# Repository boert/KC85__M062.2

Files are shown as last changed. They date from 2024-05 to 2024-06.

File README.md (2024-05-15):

# M062.2, Speichermodul für KC85
TTL-Version des Speichermodul M062 für den KC85/3..4..5 mit 32 kByte RAM (nichtflüchtig) oder 64 kByte EPROM

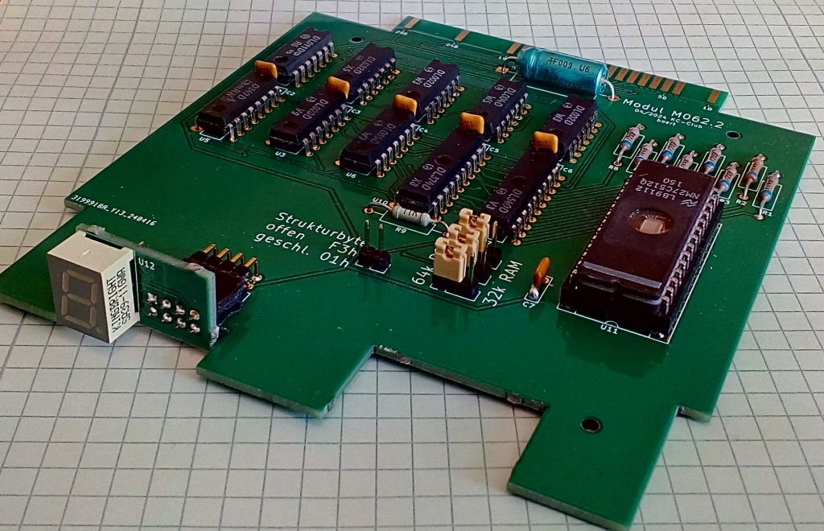
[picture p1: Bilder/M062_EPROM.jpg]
M062.2 bestückt mit 64 kByte EPROM


## Motivation
Um die Erweiterung der EPROM-Generator-Software [^1] zu testen, wurde eine passende Hardware benötigt.
Das M062 von E. Müller ist ein Speichermodul für den KC85 aus Mühlhausen, das entweder mit einem EPROM (64 kByte) oder einem nichtflüchtgen SRAM (32 kByte) bestückt werden kann. Durch den Einsatz eines CPLD werden im Original nur vier Schaltkreise benötigt.

Die hier vorgestellte Lösung entstand auf Basis einer Schaltungsbeschreibung in VHDL.
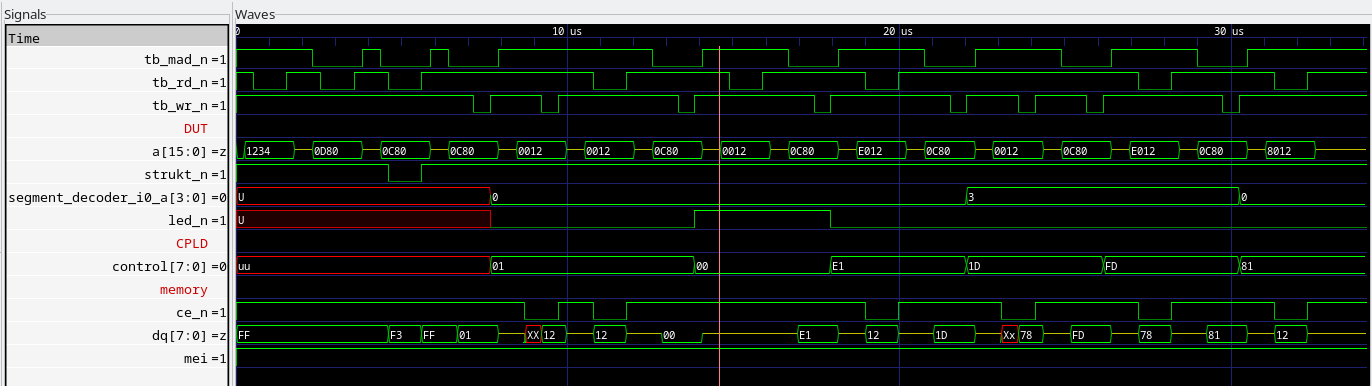
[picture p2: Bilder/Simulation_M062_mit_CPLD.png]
Simulation der Schaltungs mit ghld und Darstellung mit GTKwave

Mit Hilfe von yosys [^2] und dem ghdl-plugin [^3] ist es möglich aus der Schaltungsbeschreibung eine Netzliste zu erzeugen, die Elemente aus einer bereitgestellten TTL-Bibliothek verwendet.

<p align="center">
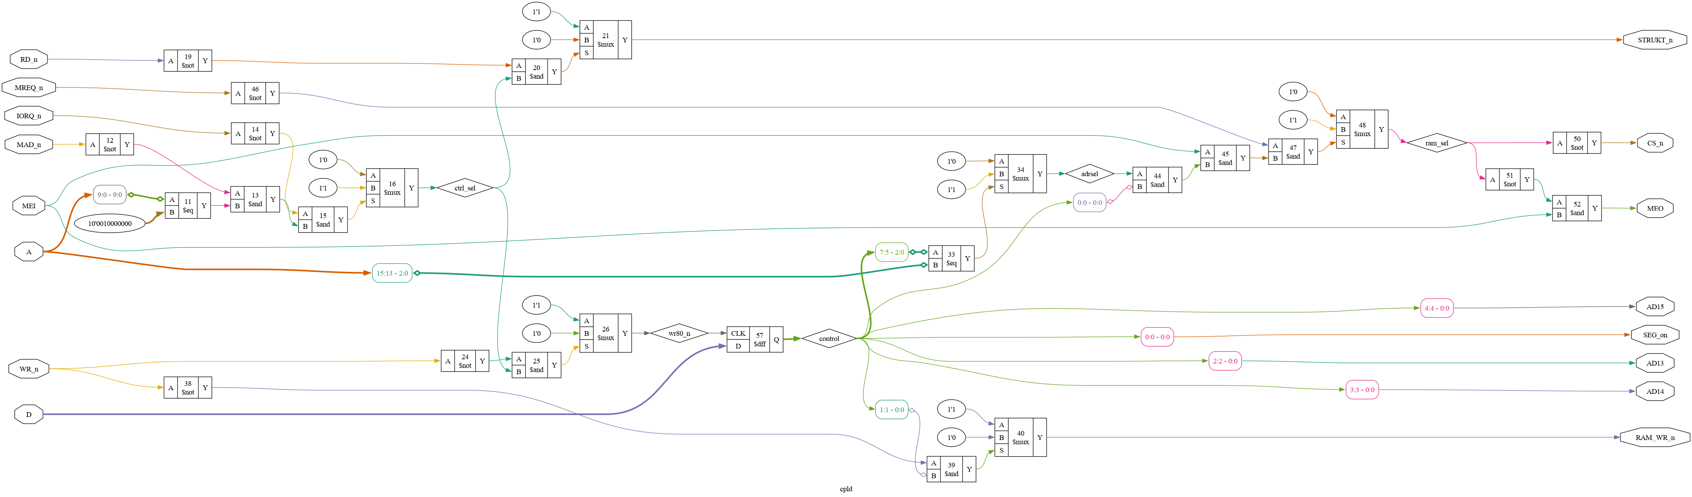
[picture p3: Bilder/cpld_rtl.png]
Synthetisierte Schaltung
  
&nbsp;
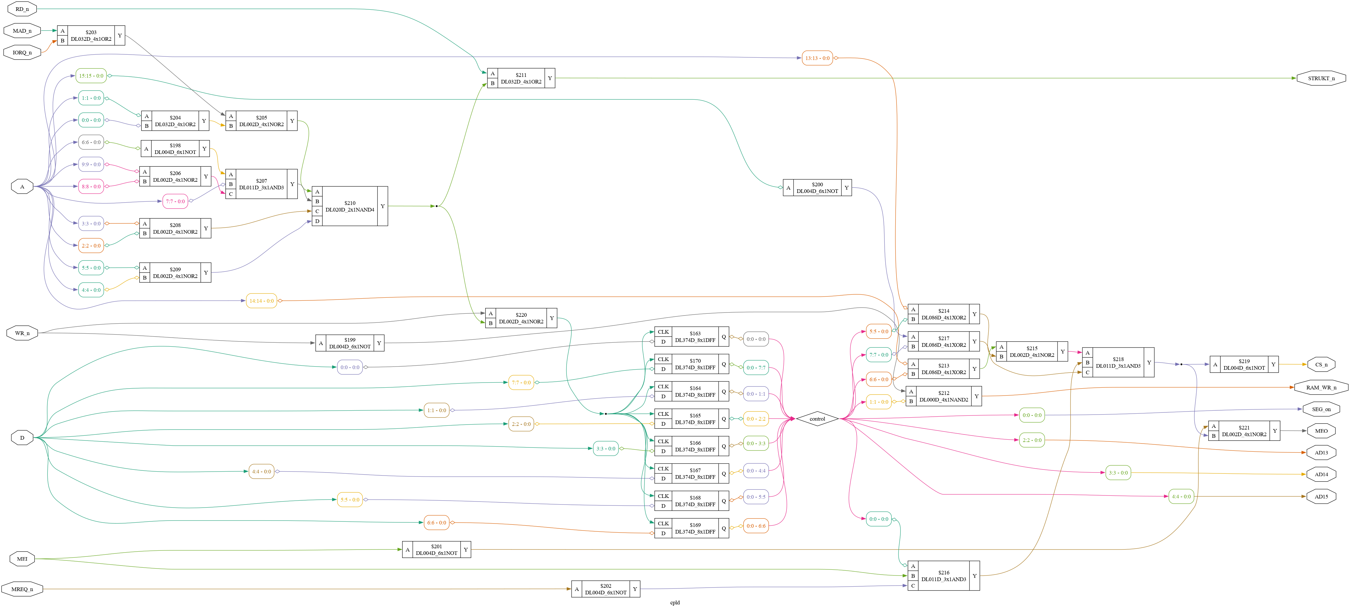
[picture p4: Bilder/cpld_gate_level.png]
Mapping auf TTL-Schaltkreise
  
</p>

Diese Netzliste wurde als Basis für den Schaltplan herangezogen.
Inklusive Speicher werden nun elf Schaltkreise benötigt.

Änderungen gegenüber dem Original
- Einsatz diskreter TTL-Schaltkreise statt CPLD
- Unterstützung für Schreibschutzbit W im Steuerbyte
- Strukturbyte zwischen F3h und 01h (Autostart) umschaltbar

Übernommen wurde die Idee mit der kleinen Zusatzplatine für die Segmentanzeige.

## Nutzung
Das Steuerbyte ist wie folgt aufgebaut:

Bit       | 7 | 6 | 5 | 4 | 3 | 2 | 1 | 0
--------- | - | - | - | - | - | - | - | -
Bedeutung | A | A | A | S | S | S | W | M

Das Speichermodul kann aus dem System CAOS mit dem Befehl SWITCH geschaltet werden.

Bit 7 | Bit 6 | Bit 5 | Adressauswahl A
----- | ----- | ----- | ---------------
0 | 0 | 0 | 0000h
0 | 0 | 1 | 2000h
0 | 1 | 0 | 4000h
0 | 1 | 1 | 6000h
1 | 0 | 0 | 8000h
1 | 0 | 1 | A000h
1 | 1 | 0 | C000h
1 | 1 | 1 | E000h

Bit 4 | Bit 3 | Bit 2 | Segment S
----- | ----- | ----- | ---------
0 | 0 | 0 | 0
0 | 0 | 1 | 1
0 | 1 | 0 | 2
0 | 1 | 1 | 3
1 | 0 | 0 | 4
1 | 0 | 1 | 5
1 | 1 | 0 | 6
1 | 1 | 1 | 7

Die Segmente 4 bis 7 existieren nur bei Bestückung mit 64 kByte EPROM.

Bit 1 | Schreibschutz W
----- | ------
0 | aktiv (read only)
1 | inaktiv (read write)

Bit 0 | Modulzustand M
----- | ------
0 | inaktiv
1 | aktiv

### Beispiel
Angenommen das Modul M062.2 steckt im Modulschacht 0C. 

Um das Segement 3 im Speicher auf Adresse 4000h im Modus Schreiben/Lesen zu aktivieren, wird der CAOS-Befehl "SWITCH C 4F" verwendet. 

Um das Segement 7 im Speicher auf Adresse C000h im Modul Nur-Lesen zu aktivieren, wird der CAOS-Befehl "SWITCH C DD" verwendet.

## Links
[^1]: https://github.com/boert/KC85__M037_segmented_ROM/tree/main/EPROM-Generator
[^2]: https://yosyshq.net/yosys/
[^3]: https://github.com/ghdl/ghdl-yosys-plugin

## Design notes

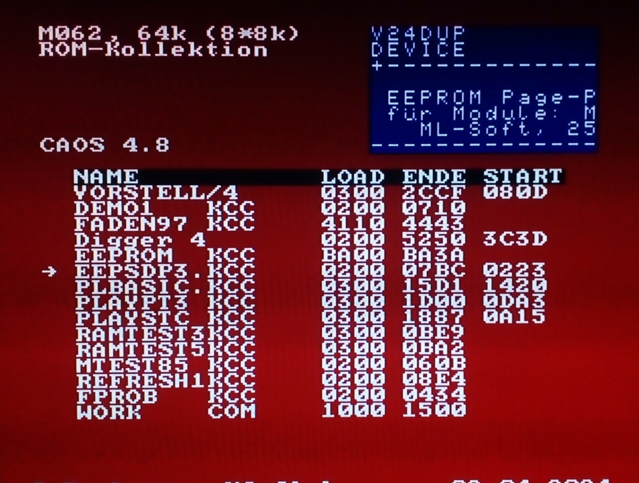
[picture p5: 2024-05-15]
EPROM-Images/M062__Utilitys_KC854.jpg

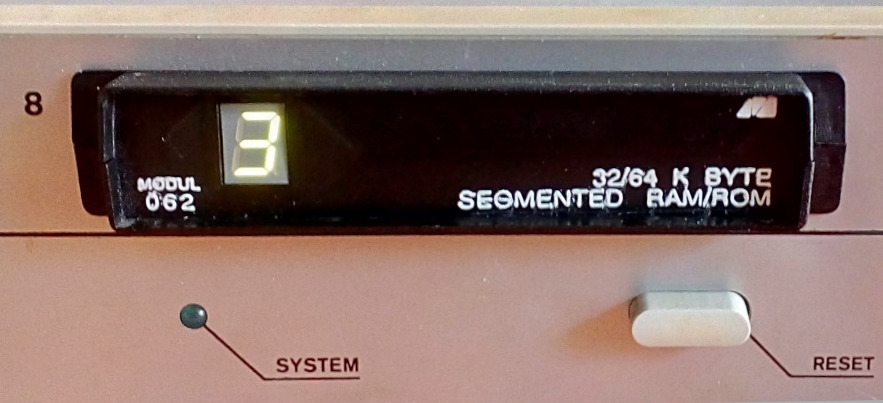
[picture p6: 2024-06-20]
Modulfrontblende__Prototyp/Bilder/M062_im_Schacht_08.jpg

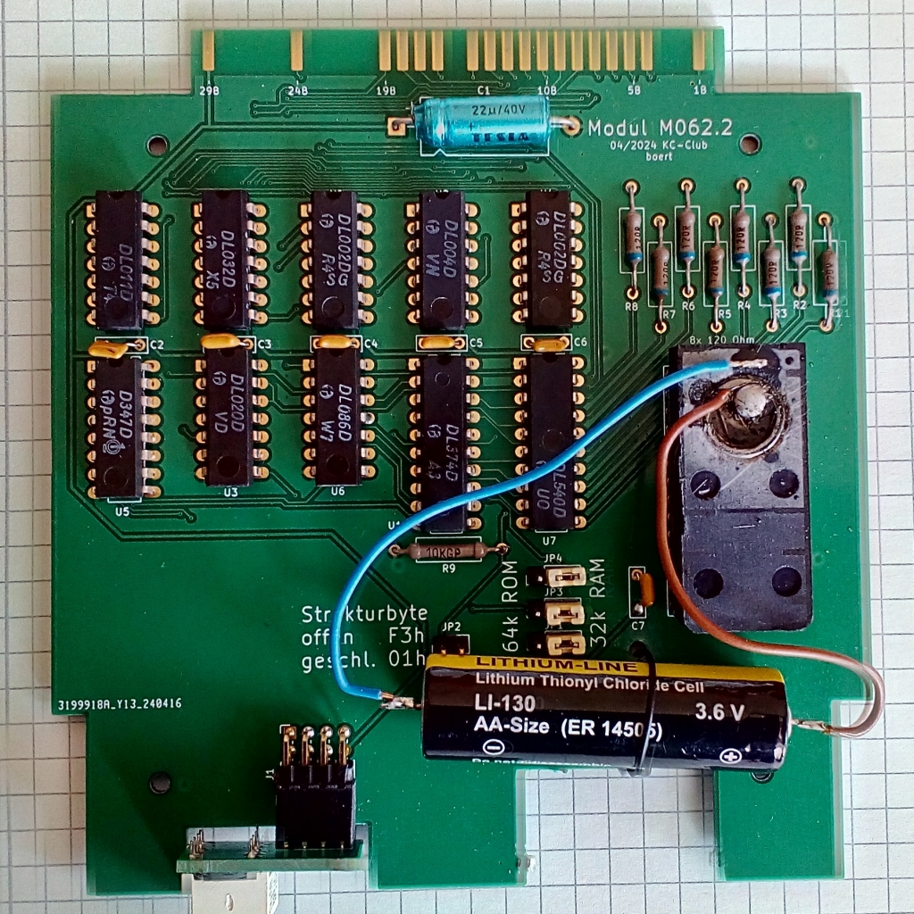
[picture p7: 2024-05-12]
Bilder/M062_NVRAM.jpg

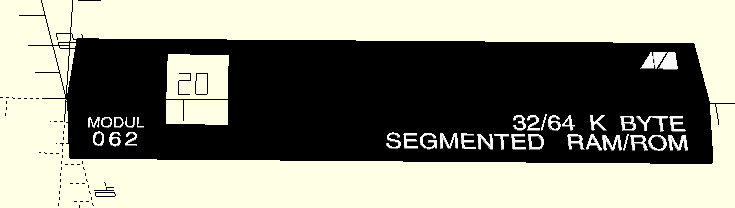
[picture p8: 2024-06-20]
Modulfrontblende__Prototyp/Bilder/M062_Frontblende__scad.png

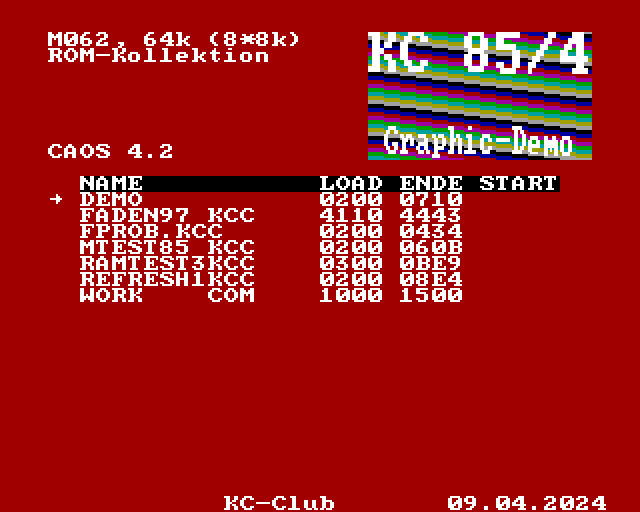
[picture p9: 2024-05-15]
EPROM-Images/M062__7_Tools_KC854.png

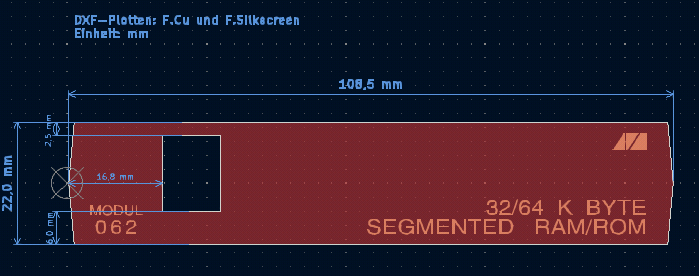
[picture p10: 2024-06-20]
Modulfrontblende__Prototyp/Bilder/M062_Frontblende__kicad.png

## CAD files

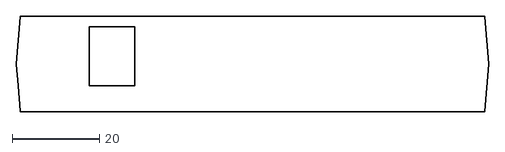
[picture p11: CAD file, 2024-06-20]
Modulfrontblende__Prototyp/DXF/M062_Frontblende-F_Cu.dxf
108.5 x 22.0

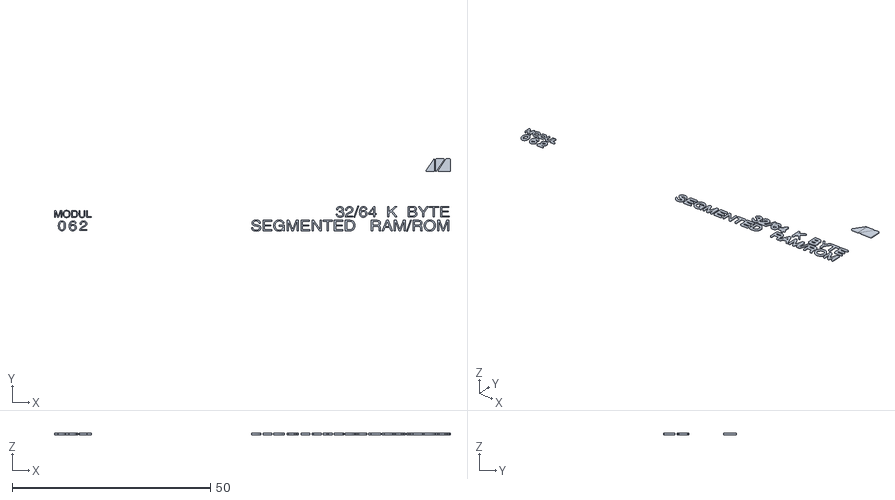
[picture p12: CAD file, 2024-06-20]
Modulfrontblende__Prototyp/OpenSCAD/M062_Frontblende__Schrift.stl
100.0 x 18.3 x 0.4

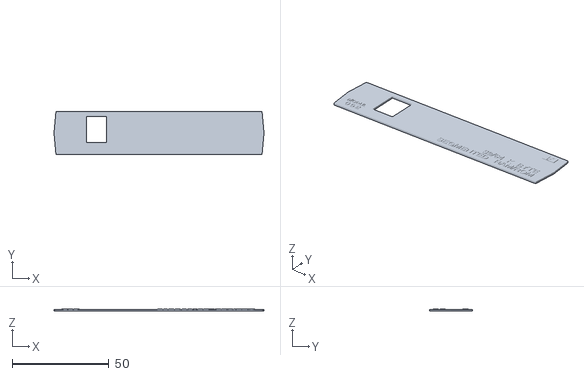
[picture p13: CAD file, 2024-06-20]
Modulfrontblende__Prototyp/OpenSCAD/M062_Frontblende__komplett.stl
108.5 x 22.0 x 1.29

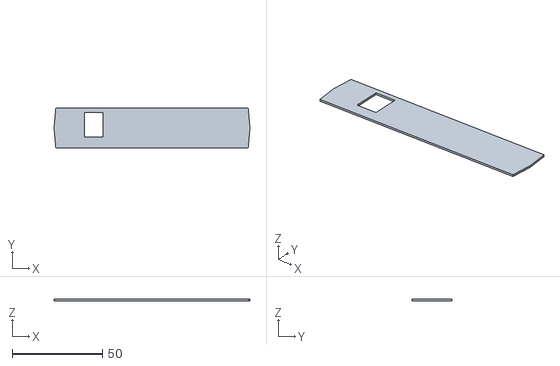
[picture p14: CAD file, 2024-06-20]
Modulfrontblende__Prototyp/OpenSCAD/M062_Frontblende__Blende_einzeln.stl
108.5 x 22.0 x 0.9

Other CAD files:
Modulfrontblende__Prototyp/OpenSCAD/M062_Frontblende.scad
Modulfrontblende__Prototyp/DXF/M062_Frontblende-F_Silkscreen.dxf

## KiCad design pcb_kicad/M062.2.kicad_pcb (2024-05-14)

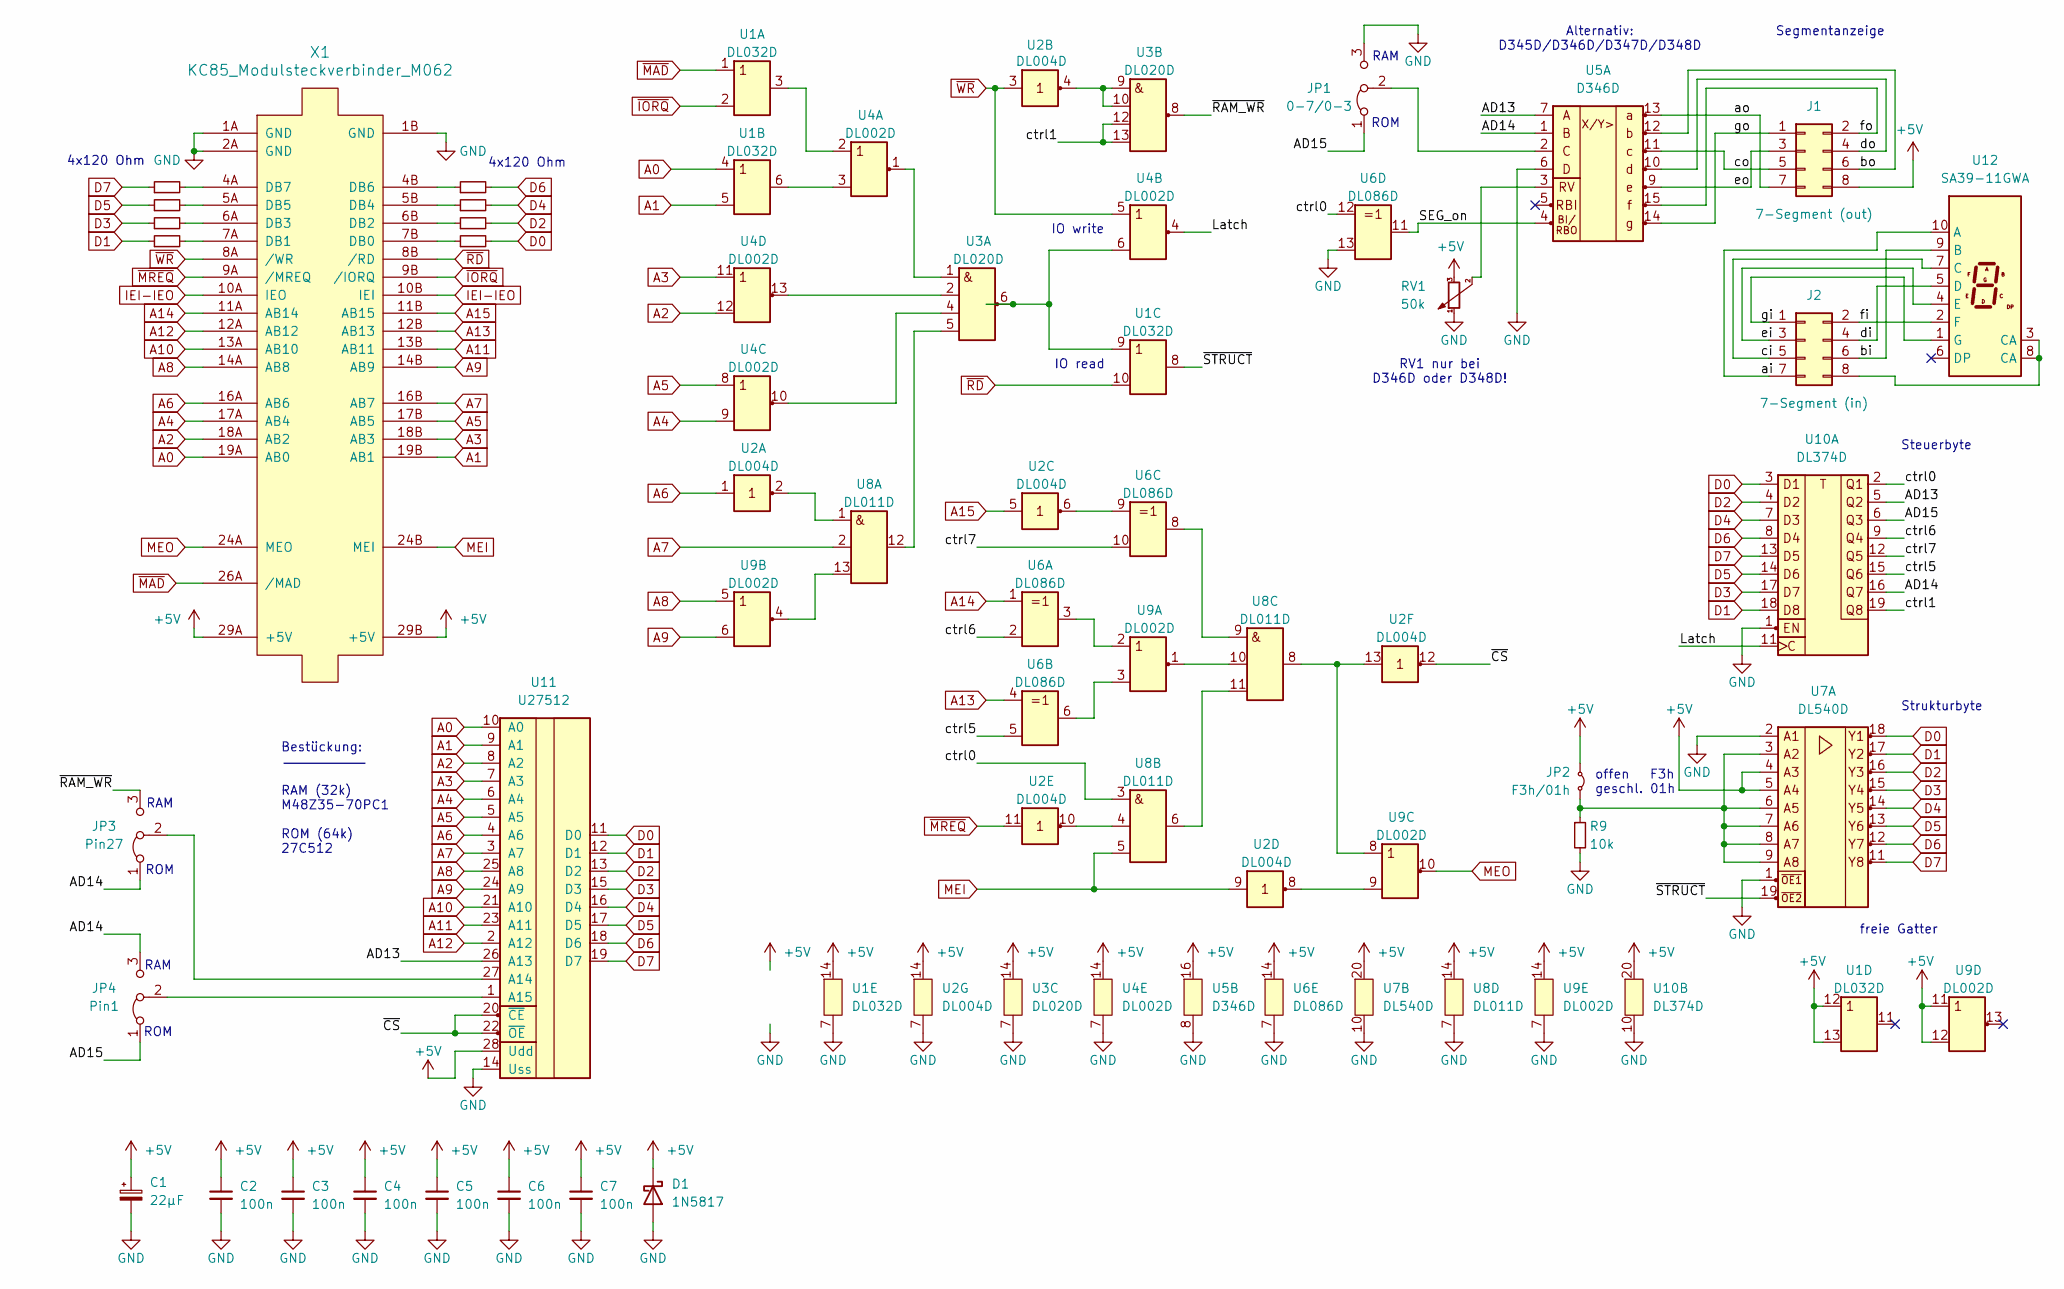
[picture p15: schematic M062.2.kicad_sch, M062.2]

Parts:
C1: 22µF; CP_Axial_L18.0mm_D8.0mm_P25.00mm_Horizontal
C2, C3, C4, C5, C6, C7: 100n; C_Rect_L7.0mm_W2.0mm_P5.00mm
D1: 1N5817; D_DO-41_SOD81_P10.16mm_Horizontal
J1: 7-Segment (out); PinSocket_2x04_P2.54mm_Horizontal
J2: 7-Segment (in); PinHeader_2x04_P2.54mm_Vertical
JP1: 0-7/0-3; PinHeader_1x03_P2.54mm_Vertical
JP2: F3h/01h; PinHeader_1x02_P2.54mm_Vertical
JP3: Pin27; PinHeader_1x03_P2.54mm_Vertical
JP4: Pin1; PinHeader_1x03_P2.54mm_Vertical
R1, R2, R3, R4, R5, R6, R7, R8: 120; R_Axial_DIN0309_L9.0mm_D3.2mm_P15.24mm_Horizontal
R9: 10k; R_Axial_DIN0309_L9.0mm_D3.2mm_P15.24mm_Horizontal
RV1: 50k; Potentiometer_ACP_CA9-V10_Vertical
U1: DL032D; DIP-14_W7.62mm_LongPads
U2: DL004D; DIP-14_W7.62mm_LongPads
U3: DL020D; DIP-14_W7.62mm_LongPads
U4, U9: DL002D; DIP-14_W7.62mm_LongPads
U5: D346D; DIP-16_W7.62mm_LongPads
U6: DL086D; DIP-14_W7.62mm_LongPads
U7: DL540D; DIP-20_W7.62mm_LongPads
U8: DL011D; DIP-14_W7.62mm_LongPads
U10: DL374D; DIP-20_W7.62mm_LongPads
U11: U27512; DIP-28_W15.24mm_Socket_LongPads
U12: SA39-11GWA; Sx39-1xxxxx
X1: KC85_Modulsteckverbinder_M062; KC85_Modul_M062

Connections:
+5V: C1.1, C2.1, C3.1, C4.1, C5.1, C6.1, C7.1, D1.1 (K), J1.8, JP2.2 (B), RV1.3, U1.12 (A4), U1.13 (B4), U1.14 (Vcc), U2.14 (Vcc), U3.14 (Vcc), U4.14 (Vcc), U5.16 (Vcc), U6.14 (Vcc), U7.4 (A3), U7.5 (A4), U7.20 (Vcc), U8.14 (Vcc), U9.11 (A4), U9.12 (B4), U9.14 (Vcc), U10.20 (Vcc), U11.28 (Udd), X1.29A (+5V), X1.29B (+5V)
/AD13: U5.7 (A), U10.5 (Q2), U11.26 (A13)
/AD14: JP3.1 (A), JP4.3 (B), U5.1 (B), U10.16 (Q7)
/AD15: JP1.1 (A), JP4.1 (A), U10.6 (Q3)
/Latch: U4.4 (Y2), U10.11 (C)
/SEG_on: U5.4 (BI/RBO), U6.11 (Y4)
/ai: J2.7, U12.10 (A)
/ao: J1.7, U5.13 (a)
/bi: J2.6, U12.9 (B)
/bo: J1.6, U5.12 (b)
/ci: J2.5, U12.7 (C)
/co: J1.5, U5.11 (c)
/ctrl0: U6.12 (A4), U8.3 (A2), U10.2 (Q1)
/ctrl1: U3.12 (C2), U3.13 (D2), U10.19 (Q8)
/ctrl5: U6.5 (B2), U10.15 (Q6)
/ctrl6: U6.2 (B1), U10.9 (Q4)
/ctrl7: U6.10 (B3), U10.12 (Q5)
/di: J2.4, U12.5 (D)
/do: J1.4, U5.10 (d)
/ei: J2.3, U12.4 (E)
/eo: J1.3, U5.9 (e)
/fi: J2.2, U12.2 (F)
/fo: J1.2, U5.15 (f)
/gi: J2.1, U12.1 (G)
/go: J1.1, U5.14 (g)
/~CS: U2.12 (Y6), U11.20 (~CE), U11.22 (~OE)
/~RAM_WR: JP3.3 (B), U3.8 (Y2)
/~STRUCT: U1.8 (Y3), U7.19 (~OE2)
A0: U1.4 (A2), U11.10 (A0), X1.19A (AB0)
A1: U1.5 (B2), U11.9 (A1), X1.19B (AB1)
A2: U4.12 (B4), U11.8 (A2), X1.18A (AB2)
A3: U4.11 (A4), U11.7 (A3), X1.18B (AB3)
A4: U4.9 (B3), U11.6 (A4), X1.17A (AB4)
A5: U4.8 (A3), U11.5 (A5), X1.17B (AB5)
A6: U2.1 (A1), U11.4 (A6), X1.16A (AB6)
A7: U8.2 (B1), U11.3 (A7), X1.16B (AB7)
A8: U9.5 (A2), U11.25 (A8), X1.14A (AB8)
A9: U9.6 (B2), U11.24 (A9), X1.14B (AB9)
A10: U11.21 (A10), X1.13A (AB10)
A11: U11.23 (A11), X1.13B (AB11)
A12: U11.2 (A12), X1.12A (AB12)
A13: U6.4 (A2), X1.12B (AB13)
A14: U6.1 (A1), X1.11A (AB14)
A15: U2.5 (A3), X1.11B (AB15)
D0: R8.2, U7.18 (Y1), U10.3 (D1), U11.11 (D0)
D1: R7.1, U7.17 (Y2), U10.18 (D8), U11.12 (D1)
D2: R6.2, U7.16 (Y3), U10.4 (D2), U11.13 (D2)
D3: R5.1, U7.15 (A4), U10.17 (D7), U11.15 (D3)
D4: R4.2, U7.14 (Y5), U10.7 (D3), U11.16 (D4)
D5: R3.1, U7.13 (Y6), U10.14 (D6), U11.17 (D5)
D6: R2.2, U7.12 (Y7), U10.8 (D4), U11.18 (D6)
D7: R1.1, U7.11 (Y8), U10.13 (D5), U11.19 (D7)
GND: C1.2, C2.2, C3.2, C4.2, C5.2, C6.2, C7.2, D1.2 (A), JP1.3 (B), R9.2, RV1.1, U1.7 (GND), U2.7 (GND), U3.7 (GND), U4.7 (GND), U5.6 (D), U5.8 (GND), U6.7 (GND), U6.13 (B4), U7.1 (~OE1), U7.2 (A1), U7.10 (GND), U8.7 (GND), U9.7 (GND), U10.1 (EN), U10.10 (GND), U11.14 (Uss), X1.1A (GND), X1.1B (GND), X1.2A (GND)
IEI-IEO: X1.10A (IEO), X1.10B (IEI)
MEI: U2.9 (A4), U8.5 (C2), X1.24B (MEI)
MEO: U9.10 (Y3), X1.24A (MEO)
unnamed: J2.8, U12.3 (CA), U12.8 (CA)
unnamed: JP1.2 (C), U5.2 (C)
unnamed: JP2.1 (A), R9.1, U7.3 (A2), U7.6 (A5), U7.7 (A6), U7.8 (A7), U7.9 (A8)
unnamed: JP3.2 (C), U11.27 (A14)
unnamed: JP4.2 (C), U11.1 (A15)
unnamed: U1.3 (Y1), U4.2 (A1)
unnamed: U1.6 (Y2), U4.3 (B1)
unnamed: U1.9 (A3), U3.6 (Y1), U4.6 (B2)
unnamed: U2.2 (Y1), U8.1 (A1)
unnamed: U2.4 (Y2), U3.9 (A2), U3.10 (B2)
unnamed: U2.6 (Y3), U6.9 (A3)
unnamed: U2.8 (Y4), U9.9 (B3)
unnamed: U2.10 (Y5), U8.4 (B2)
unnamed: U2.13 (A6), U8.8 (Y3), U9.8 (A3)
unnamed: U3.1 (A1), U4.1 (Y1)
unnamed: U3.2 (B1), U4.13 (Y4)
unnamed: U3.4 (C1), U4.10 (Y3)
unnamed: U3.5 (D1), U8.12 (Y1)
unnamed: RV1.2, U5.3 (RV)
unnamed: U6.3 (Y1), U9.2 (A1)
unnamed: U6.6 (Y2), U9.3 (B1)
unnamed: U6.8 (Y3), U8.9 (A3)
unnamed: U8.13 (C1), U9.4 (Y2)
unnamed: U8.6 (Y2), U8.11 (C3)
unnamed: U8.10 (B3), U9.1 (Y1)
unnamed: R8.1, X1.7B (DB0)
unnamed: R7.2, X1.7A (DB1)
unnamed: R6.1, X1.6B (DB2)
unnamed: R5.2, X1.6A (DB3)
unnamed: R4.1, X1.5B (DB4)
unnamed: R3.2, X1.5A (DB5)
unnamed: R2.1, X1.4B (DB6)
unnamed: R1.2, X1.4A (DB7)
~IORQ: U1.2 (B1), X1.9B (/IORQ)
~MAD: U1.1 (A1), X1.26A (/MAD)
~MREQ: U2.11 (A5), X1.9A (/MREQ)
~RD: U1.10 (B3), X1.8B (/RD)
~WR: U2.3 (A2), U4.5 (A2), X1.8A (/WR)

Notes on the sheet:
Steuerbyte
ROM
4x120 Ohm
IO read
IO write
Strukturbyte
RV1 nur bei D346D oder D348D!
RAM
freie Gatter
Bestückung: RAM (32k) M48Z35-70PC1 ROM (64k) 27C512
offen F3h geschl. 01h
Segmentanzeige
Alternativ: D345D/D346D/D347D/D348D

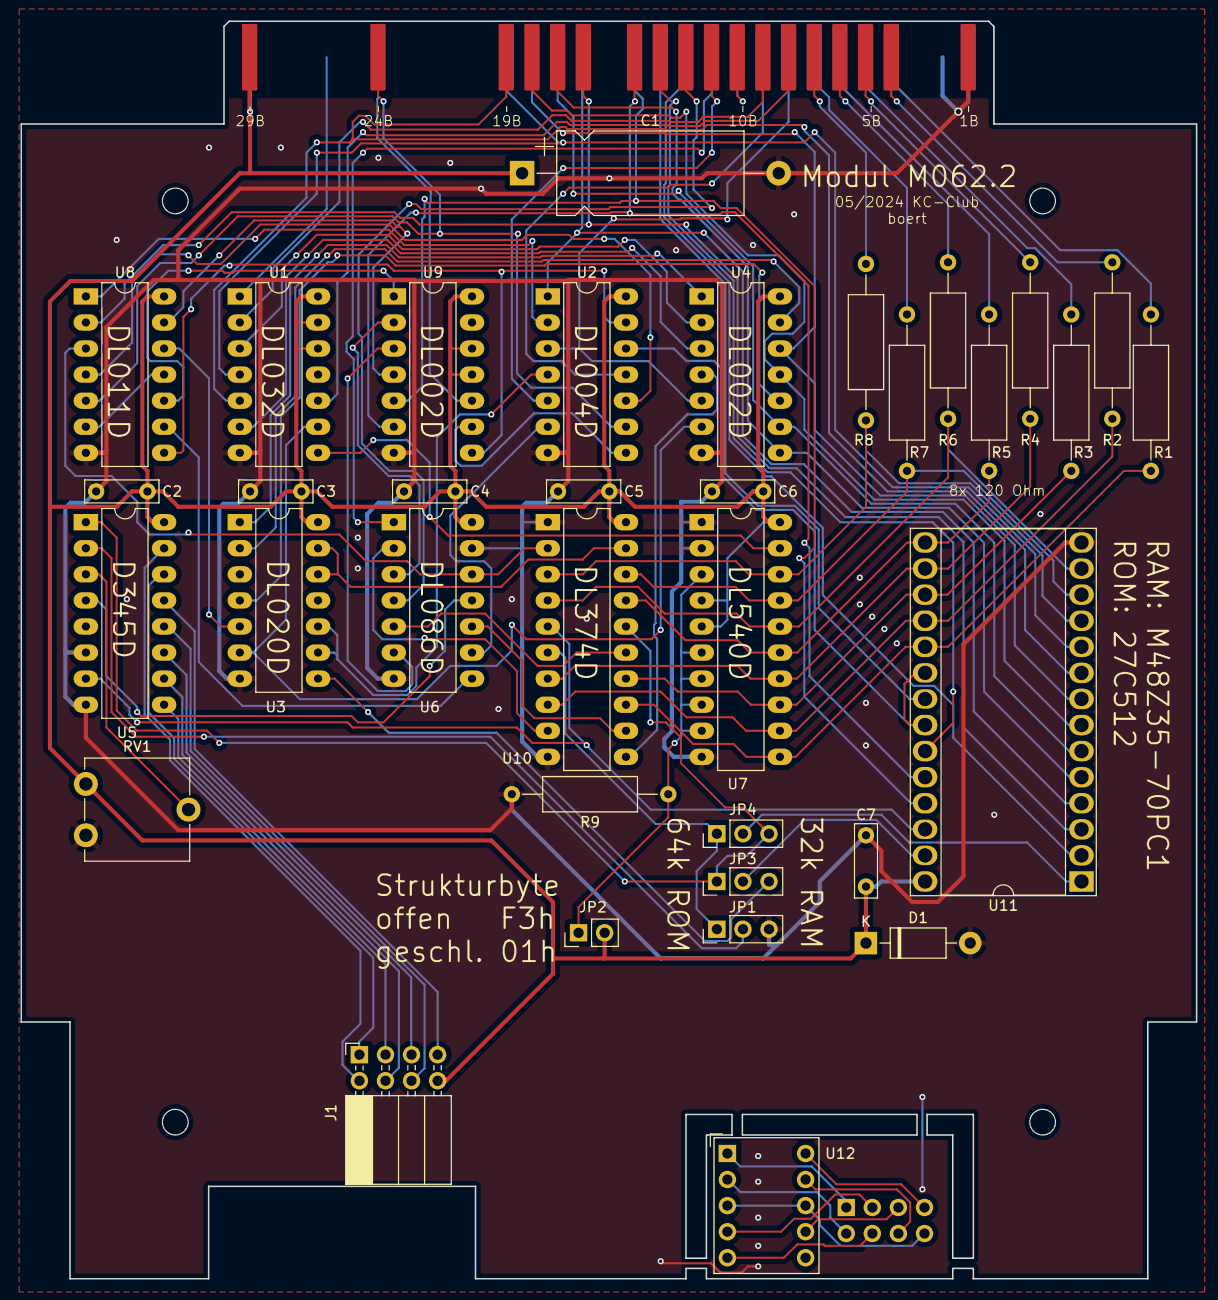
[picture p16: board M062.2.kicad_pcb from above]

Board: 2 copper layers, 114.5 x 122.5 mm, 37 parts (1 on the bottom side), 94 nets.

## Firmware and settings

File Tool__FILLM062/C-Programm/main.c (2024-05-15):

//--------------------------------------------------------------------------
//  main.c
//
//  Copyright (C) 2024, Bert Lange
//
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
//  As a special exception, if you link this library with other files,
//  some of which are compiled with SDCC, to produce an executable,
//  this library does not by itself cause the resulting executable to
//  be covered by the GNU General Public License. This exception does
//  not however invalidate any other reasons why the executable file
//   might be covered by the GNU General Public License.
//--------------------------------------------------------------------------


#include <stdio.h>
#include <stdint.h>
#include "caos.h"

// Prototypen

// Speicherstellen
volatile __at (0xB7A0) uint8_t IRM_CURSO;
volatile __at (0xB7A2) uint8_t IRM_STBT;
volatile __at (0xB7A3) uint8_t IRM_COLOR;
volatile __at (0xB800) uint8_t IRM_MODST[256];

// Hilfskonstanten
const uint8_t mod_off = 0;
const uint8_t mod_ro = 1;
const uint8_t mod_rw = 3;

const char filename_seg0[] = "M062SEG0.KCC";
const char filename_seg1[] = "M062SEG1.KCC";
const char filename_seg2[] = "M062SEG2.KCC";
const char filename_seg3[] = "M062SEG3.KCC";

// Hilfsfunktionen
#define hi(x)   ((x) >> 8)
#define lo(x)   ((x) & 0xff)


uint8_t modul_search( const uint8_t struct_byte)
{
    uint8_t slot;
    uint16_t value;

    for( slot = 8; slot < 255; slot++)
    {
        value = modu( 1, slot, 0);
        if( hi( value) == struct_byte)
        {
            return slot;
        }
    }
    return 0;
}


void main( void)
{
    uint8_t ram4_state;
    uint8_t segment;
    uint8_t m062_slot;

    m062_slot = modul_search( 0xF3);
    ram4_state = IRM_MODST[4];

#if 0
    // Debug
    printf( "M062 slot: %02X\n", m062_slot);
    printf( "RAM4 state: %02X\n", ram4_state);
#endif

    if( m062_slot > 0)
    {
        printf( "M062.2 (32k-RAM-Version)\nin Schacht %02X bef\x7dllen\n", m062_slot);
    }
    else
    {
        printf( "Modul M062 nicht gefunden.\n");
        return;
    }

    printf( "RAM 4 abschalten\n");
    modu( 2, 4, mod_off);


    printf( "Segment 0...");
    segment = 0;
    modu( 2, m062_slot, 0x40 + (segment << 2) + mod_rw);
    load( filename_seg0);


    printf( "Segment 1...");
    segment = 1;
    modu( 2, m062_slot, 0x40 + (segment << 2) + mod_rw);
    load( filename_seg1);


    printf( "Segment 2...");
    segment = 2;
    modu( 2, m062_slot, 0x40 + (segment << 2) + mod_rw);
    load( filename_seg2);


    printf( "Segment 3...");
    segment = 3;
    modu( 2, m062_slot, 0x40 + (segment << 2) + mod_rw);
    load( filename_seg3);


    printf( "M062 deaktivieren\n");
    modu( 2, m062_slot, mod_off);


    printf( "RAM 4 zur\x7dcksetzen\n");
    modu( 2, 4, ram4_state);

    return;
}

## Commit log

2024-05-12 add: lots of files
    [M062.2-B_Cu.gbr, M062.2-B_Mask.gbr, M062.2-B_Paste.gbr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]
2024-05-14 change: Bohrungen für Speicherchip vergößert
    [M062.2-B_Cu.gbr, M062.2-B_Mask.gbr, M062.2-B_Paste.gbr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]
2024-06-20 add: Frontblende
    [M062_Frontblende-F_Cu.dxf, M062_Frontblende-F_Silkscreen.dxf, M062_Frontblende.kicad_pcb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]

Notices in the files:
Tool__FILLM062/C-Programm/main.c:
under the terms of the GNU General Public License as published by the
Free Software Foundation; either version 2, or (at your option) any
